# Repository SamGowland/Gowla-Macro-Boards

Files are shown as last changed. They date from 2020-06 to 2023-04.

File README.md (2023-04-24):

# Gowla-Macro-Boards 

 - [Gowla Macro Board V1](#Gowla-Macro-Board-V1) <b> :heavy_check_mark: </b>
   - 9 Key Macro board for MX style switches.
 - [Gowla-Macro-eRGB](#Gowla-Macro-eRGB) <b> :heavy_check_mark: </b>
   - 9 Key Macro Board with easy underglow RGB and Rotary Encoder support.
 - [MEK-Light | Tapedeck - Soon to be available, following QMK approval 2023 </b>](#MEK-Light-RGB) <b>:x:</b>
   - 12 Key editing keyboard with 60mm fader or 30mm + oled, two rotary encoders and underglow lighting. 
 - [Gowla Keyboard-1](#Gowla-Keyboard-1) <b>:x:</b>
   - 44 key Ortho Keyboard built around the Pi Pico with Encoders, Sliders and Glow. In the works. 
   
<b> :heavy_check_mark: Available</b> <b>:x: Not Available</b>

<i> For fully built macro keyboards with cases, follow my [eBay store](https://www.ebay.co.uk/usr/gowla.2014/) as these will only be listed when I have parts available. </i>

<p align="center">
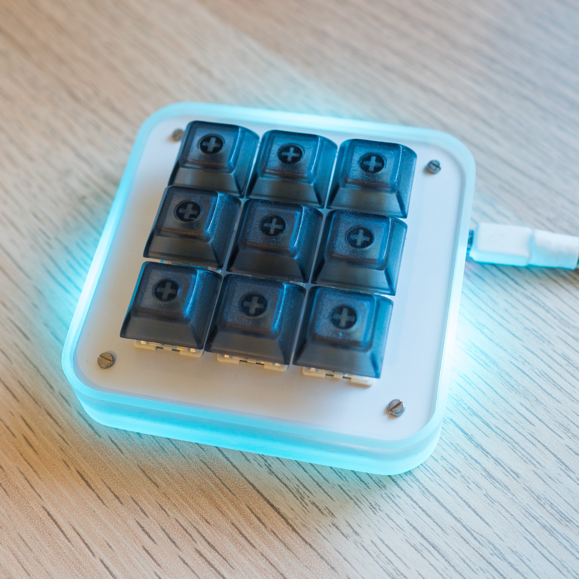
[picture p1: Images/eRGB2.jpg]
 
 
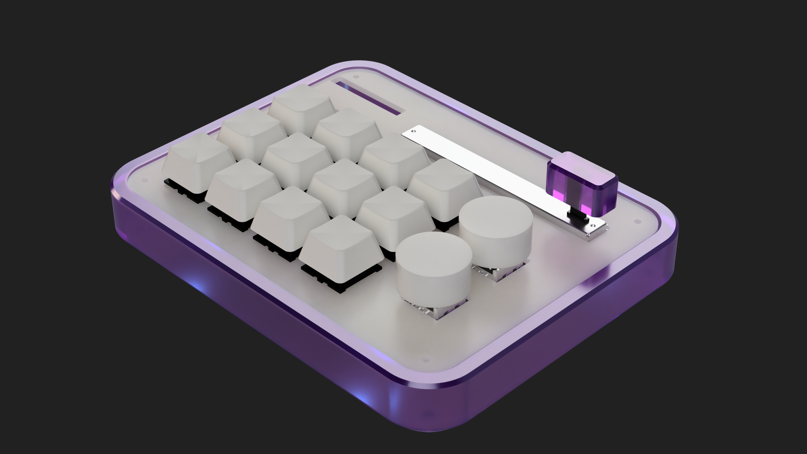
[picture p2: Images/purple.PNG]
 
</p>

 ---

# Gowla-Macro-Board-V1

Version 1 PCB is where this project all started and is available to buy, it's fully supported in QMK and super simple to put together! Great for practicing your soldering skills and getting started into mechanical keyboards. 

<p align="center">
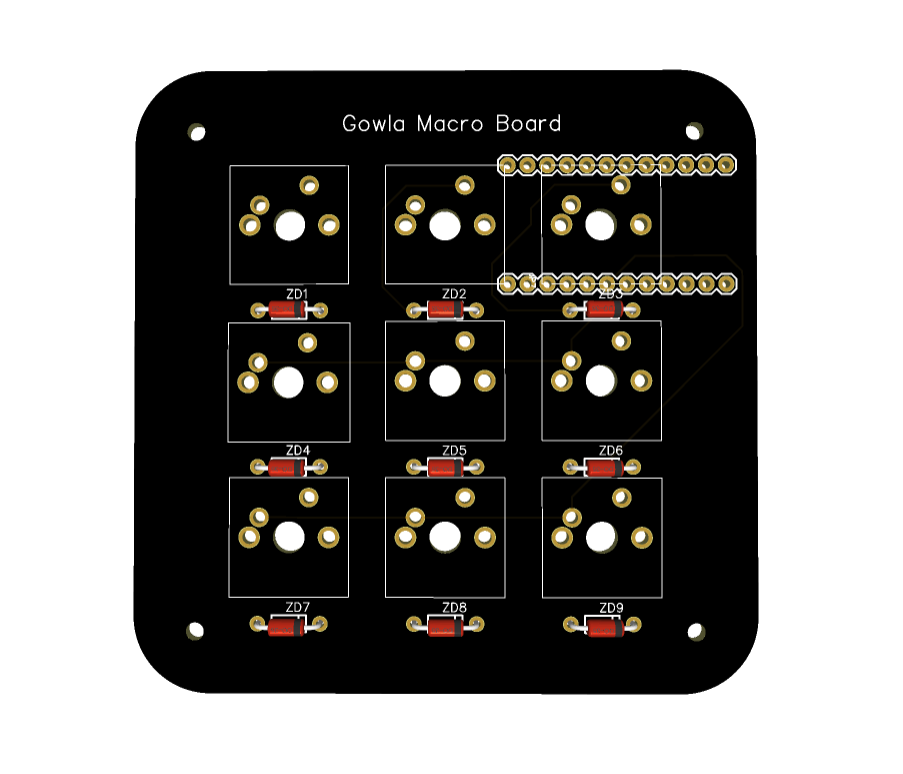
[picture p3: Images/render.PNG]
  
</p>

## Purchase

To purchase a PCB for DIY assembly and to support this project please visit my [eBay Page](https://www.ebay.co.uk/usr/gowla.2014/).

For additional options such as plates, hardware, RGB and more visit the <b>new!</b> multi variation page : [Variations eBay Page](http://www.ebay.co.uk/itm/164521787563)

## Required Parts

- 1 x Pro Micro ATMEGA32U4 5V 16MHz (Micro USB) - Sparkfun/Clone Size
- 9 x 1N4148 Diodes.
- 9 x PCB or Plate Mount Switches (Cherry MX or Clones).
- 9 x Key Caps.
- 8 x *<i>M2, 6mm (min) to 10mm (max) body length + 3mm thread Stand Off Spacers Male-to-Female</i>
  
  > Please note there's a variety of different hardware options. At a minimum you will need your PCB 6mm off the ground, though for the best compatibility I would recommend 8mm. 

## Assembly

Asssembly will require the use of a soldering iron, solder and some tape is recommended for holding components. <b>The order of assembly is important for the complete 9 switches. </b>

 1. Start by folding the legs of your diodes, with approx 3mm of space either side of the diode in wire. 
 
 2. Pull all diodes through the pcb holes, making sure the direction of the diode matches the image printed on the PCB. With the black mark in the direction towards the line. 
 
 3. Solder your diode legs and then cut the excess, leaving a little length for error. 
 
 4. Next solder in your top 3 switches. 
 
 5. Then solder in and/or socket your pro micro, you will at a minimum need the [headers](https://i.ebayimg.com/images/g/YPwAAOSwV3JeY9c1/s-l1600.jpg) provided with most when ordered. Making sure the pro micro usb is pointing outwards away from PCB and on the underside of the PCB. 
 
 <p align="center">
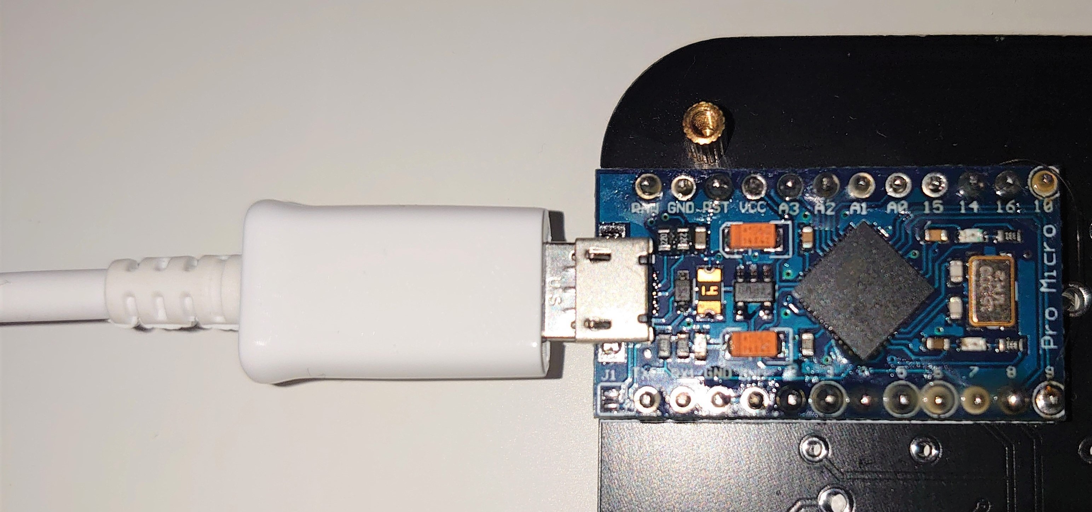
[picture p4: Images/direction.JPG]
  
</p>
 
 6. Once the Pro Micro is in, continue to solder your remaining switches. 
 
 7. Finish by adding key caps and screws, then move onto programming or flashing the firmware.
 
 <p align="center">
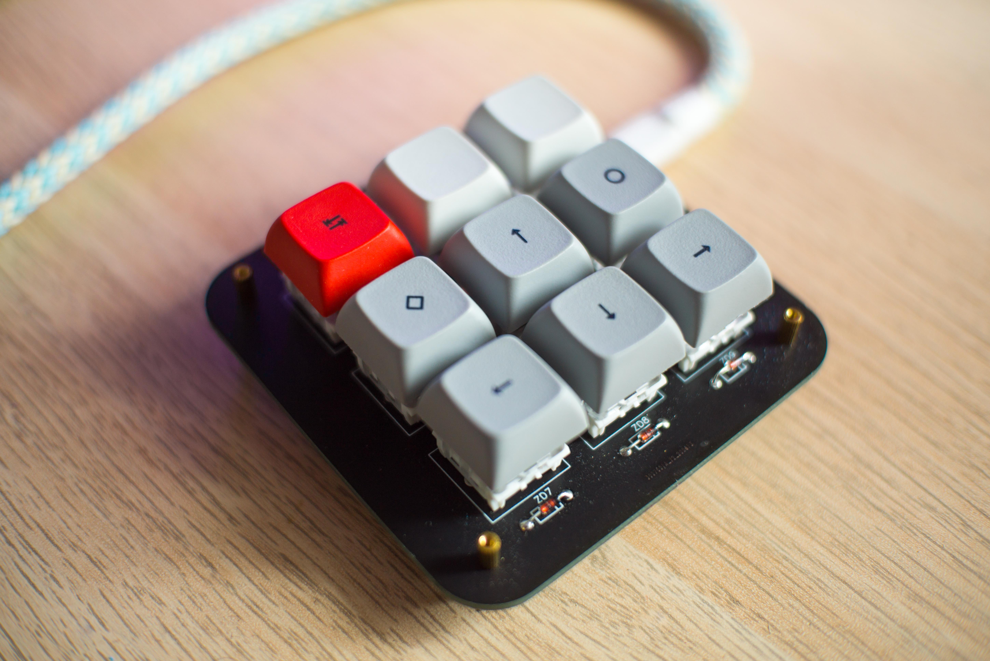
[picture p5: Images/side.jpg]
  
</p>

---
## Simple Programming

You can build and compile new keyboard layouts most simply by using the web configurator : https://config.qmk.fm/#/gowla/LAYOUT_ortho_3x3

For more advanced programming follow the [QMK tutorials](https://beta.docs.qmk.fm/tutorial).

The [default build](https://github.com/qmk/qmk_firmware/tree/master/keyboards/gowla) is also available for use through QMK toolbox and files available within the QMK Firmware repository.

## Prebaked Firmware Profiles

 1. <a href='Hex Profiles/gowla_default.hex'> Default </a><br>
 2. <a href='Hex Profiles/arrows_media.hex'> Arrows & Media </a><br>
 3. <a href='Hex Profiles/functions_gui.hex'> Fuctions & Gui </a><br>
 4. <a href='Hex Profiles/nav_media.hex'> Navigation and Media </a><br>
 
 <i>Images for each of the profiles can be found in the [images directory](https://github.com/SamGowland/Gowla-Macro-Board/tree/master/Images).</i>
 
 If you wish to add your template for other users to use, please create 
 [an issue](https://github.com/SamGowland/Gowla-Macro-Board/issues), prefixing the
issue name with "Profile".

## Flashing a Pro Micro

To flash a pro micro with your newly built or prebaked firmware you must get it into DFU mode, short the reset and ground pins. Shorting once will put into DFU for 750ms, you can use QMK toolbox to dectect DFU and automatically flash once detected. 

Double resets, to keep the pro micro in DFU mode for longer short reset and ground twice quickly. This will keep it in DFU mode upto 8 seconds allowing you to manually flash the pro micro with QMK toolbox or AVRdudess GUI. 

You can use either of the following software to flash your pro micro. 
- [QMK toolbox](https://github.com/qmk/qmk_toolbox/releases).
- [AVRdudess](https://blog.zakkemble.net/avrdudess-a-gui-for-avrdude/).

---

## Top Plates

To further improve aesthetics an additional top plate is available to buy, top plates only come in gloss white from now on. Matte blacks were experimented with but scratch too easily. <b> These are available to buy now </b> at the new multi variation ebay listing, along with new white PCBs:  [eBay Page](http://www.ebay.co.uk/itm/164521787563)

Top plates require additional hardware, M2 hardware is inculuded when purchasing a Top Plate. 3mm spacers between the plate and the PCB. 8mm spacers and 8mm M2 machine screws. 

<p align="center">
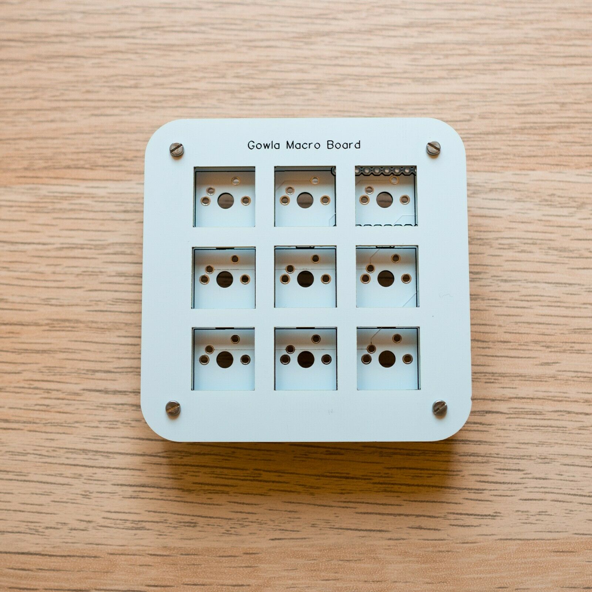
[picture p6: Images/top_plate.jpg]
  
</p>

## Case in the works

Currently I am working towards a low cost case design and intend it to look like the render below. The case will work with any updated PCB designs. So far I have designed and 3D printed these. But to improve surface finish and reduce print time the top plates will be laser cut. Top plates will be available in either black and white. 

STL files are provided for the case design within this repository. However you will need some additonal M2 hardware and no assembly instructions are currently provided. 

<p align="center">
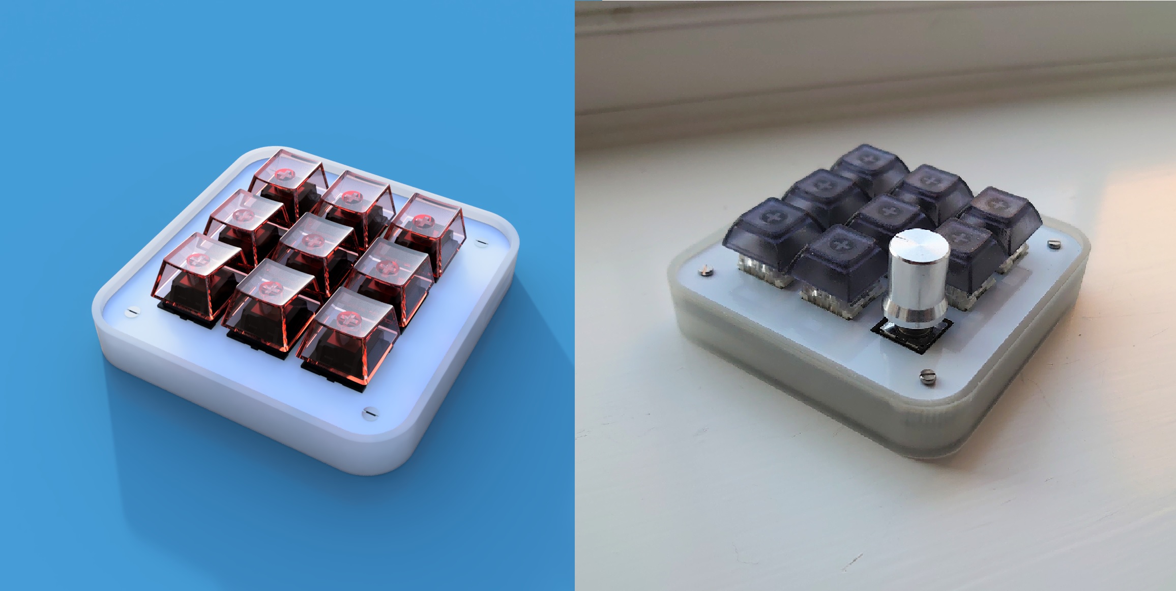
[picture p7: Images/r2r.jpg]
  
</p>

---

# Gowla-Macro-eRGB

Designed to make RGB lighting as easy as possible and add support for an optional rotary encoder (Alps EC11)

On sale now through the [Variations eBay Page](http://www.ebay.co.uk/itm/164521787563)

eRGB is backwards compatible with V1 firmware, <b> you maybe recieve an eRGB board if you order pcb only </b>. These can be assembled as V1s or with the additional features. 

<p align="center">
  
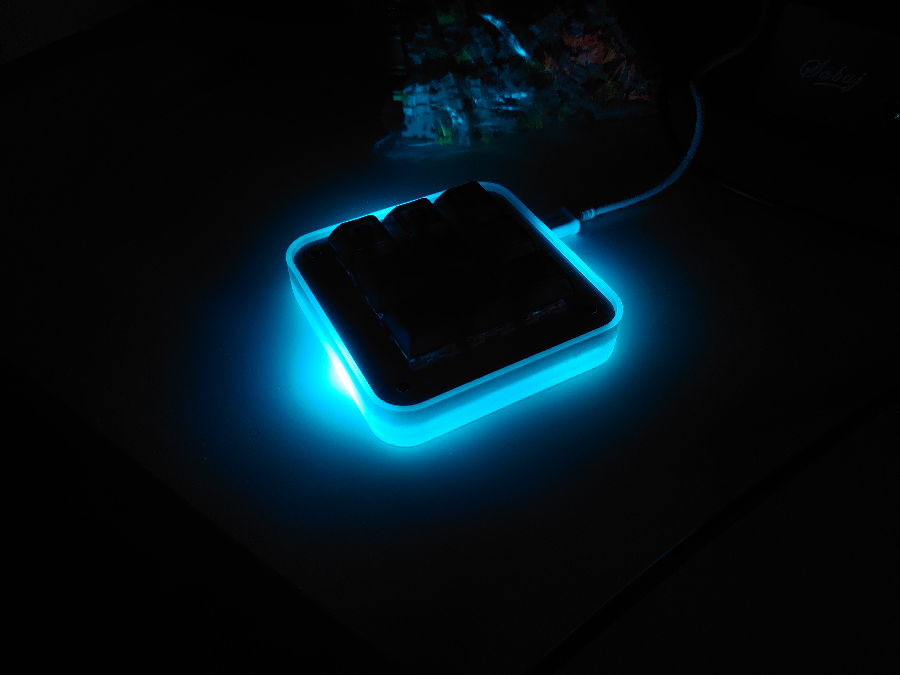
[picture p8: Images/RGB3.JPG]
 
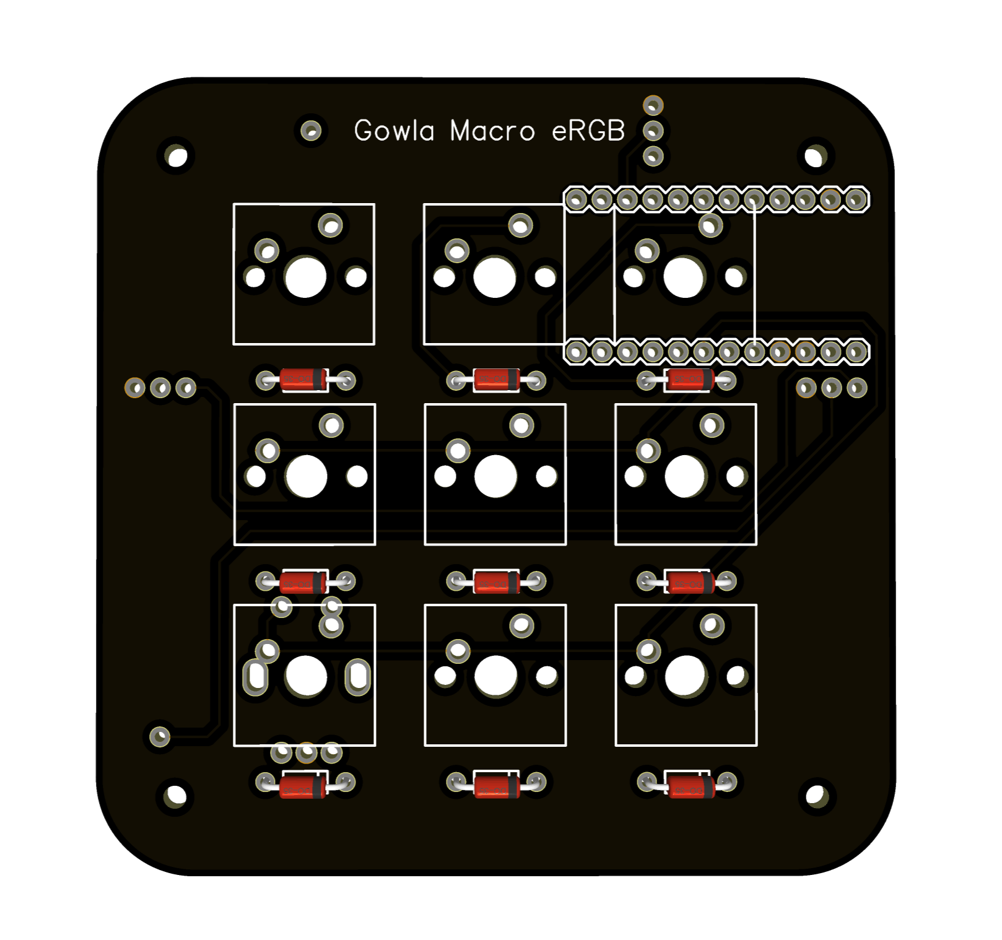
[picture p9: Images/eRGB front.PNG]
  
</p>

Some Assembly Tips (In order): 

When building take your time, and keep in mind not to block anything off before soldering it :)

- Start by soldering all your diodes into place. 
- Solder the pin headers for your pro micro but not the pro micro it's self yet. 
- Connect the plate to the PCB with 3mm spacers using the 8mm M2 scerws between the PCB and Top Plate or push switches through plate first. Head of machine screw will be on top the top plate, going through both the spacer and PCB into the 8mm bottom spacer. You may need to trim the height of the headers on the top side so they don't block the top plate. You could place switches into top plate first either. 
- Push your switches into plate and through the PCB, soldering down all your switches or 8 if your doing bottom left as rotary encoder. 
- Solder the Pro micro to the pin headers. 
- Solder RGB LEDs and rotary encoder if applicable. 

## eRGB Firmware

The firmware process for eRGB is a bit more involved at the moment, until it's no longer early access. 

Example firmware is provided within [eRGB Folder](https://github.com/SamGowland/Gowla-Macro-Boards/tree/master/eRGB/).

Please note, the following lines differ in config.c for black and white PCBs, black eRGB are an older revision. 

For white PCBs encoder and RGB pins should match this, surrounding code is not shown just update the 3 lines. 

```c
/* RGB */
#define RGB_DI_PIN B6

...

/* Rotary Encoder*/
#define ENCODERS_PAD_A { B2 }
#define ENCODERS_PAD_B { B3 }
```

 ---

# MEK-Light-RGB

coming very soon. 

[Demo Video](https://www.youtube.com/watch?v=-6GdU5GIuqY).

<p align="center">
  
</p>

## Kit Options

- Build Kit 1: 
  - Link: 
  - Included Parts: PCB, Top Plate, Alps 60mm Dual Linear Pot, 3 x RGB LEDs, Diodes, 330R Resistor, M2 Assembly Hardware
  - Required Parts: Pro Micro 5V, 2 x Alps EC11, MX Switches, Keycaps
- Build Kit 2: 
  - Link: 
  - Included Parts: Kit 1, Bottom Case, 2 x Alps EC11
  - Required Parts: Pro Micro 5V, MX Switches, Keycaps

## Build Guide

Straight forward but will require the use of a soldering iron, solder, wire cutters, time and maybe some tape for holding components. Before starting check you have all the required parts. 

Note: Order of Assembly matters, don't start with switches. 

<p align="center">
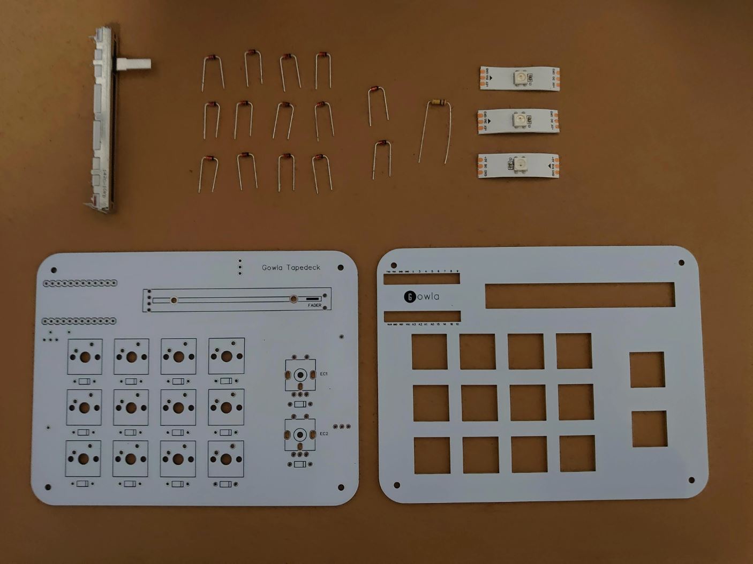
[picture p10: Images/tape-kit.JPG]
  
</p>

1. Start by folding the legs of your 14 diodes, with approx 3mm of space either side of the diode in wire.

2. Pull all diodes through the PCB holes, making sure the direction of the diode matches the image printed on the PCB. Note the direction of diodes is different for the two encoders.

3. Solder your diode legs and cut the excess.

4. Solder the 330 Ohm resistor marked on the backside. 

5. Then solder in and/or socket your pro micro, you will at a minimum need the headers provided with most when ordered. Making sure the pro micro usb is pointing outwards away from PCB and on the underside of the PCB.

6. Solder the Encoders to the PCB.

7. Solder the 60MM fader to the PCB. 

8. Grab your top plate, place the long M2 machine head screws through the plate and thread the 2mm spacer up to the top plate just like this image. 

9. Attach your top plate to the PCB by threading the gold standoffs on the machine head screws going through both the top plate and PCB. 

<p align="center">
  
</p>

10. Push down your switches into the top plate, soldering the pins connected to the PCB. 

11. Place your 3 x adhesive RGBs between the marked positions on the backside of the PCB, ensuring they match the correct direction (DI to DO) and solder between the pad and bridge. As shown here below. 

<p align="center">
  
</p>

12. Dress up with Keycaps and Knobs. Then Flash an example or custom firmware and play with your board! 

 ---
 
 ## Usage and EULA 

Design and profiles are made freely available for personal usage only and no further commercial usage. By downloading or using files within this repository users agree to not resell or redistribute the designs or files. 

## Additional Use Cases

Find additional use cases for the PCB within the [Uses directory](https://github.com/SamGowland/Gowla-Macro-Board/tree/master/Uses), a nice example is [dan-r's](https://github.com/dan-r) IR Remote use case. 

---

## Maintainers

* [Gowla](https://github.com/SamGowland)

## Getting Help

Please report issues you encounter to the
*Gowla-Macro-Board*
[Issue Tracker](https://github.com/SamGowland/Gowla-Macro-Board/issues), prefixing the
issue name with "Macro".

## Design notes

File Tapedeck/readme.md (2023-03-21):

# Gowla Tapedeck

Image of Tapedeck

4x4 12 Key Macro Board with 60MM Slider, RGB and 2 X Rotary Encoders. For use with QMK, designed and sold by Gowla.

* Keyboard Maintainer: [Gowla](https://github.com/SamGowland/)
* Hardware Supported: Pro Micro ATmega32U4, Cherry MX Switches, Alps 60MM Slider
* Hardware Availability: [Repo](https://github.com/SamGowland/Gowla-Macro-Boards)

Make example for this keyboard (after setting up your build environment):

    make tapedeck:default
    
Flashing example for this keyboard:

    make tapedeck:default:flash

See the [build environment setup](https://docs.qmk.fm/#/getting_started_build_tools) and the [make instructions](https://docs.qmk.fm/#/getting_started_make_guide) for more information. Brand new to QMK? Start with our [Complete Newbs Guide](https://docs.qmk.fm/#/newbs).

## Bootloader

Enter the bootloader in 3 ways:

* **Bootmagic reset**: Hold down the top-left key (underneath the Pro Micro) and plug in the keyboard. This will also clear EEPROM, so it is a good first step if the keyboard is misbehaving.
* **Physical reset**: Remove the back plate and short the `RST` and `GND` pins on the Pro Micro.
* **Keycode in layout**: There is no key mapped to `QK_BOOT` in the pre-created keymaps, but you may assign this key in any keymaps you create.

As a Pro Micro-compatible board, the Gowla Tapedeck uses `caterina` as its bootloader by default. Many popular Pro Micro alternatives like the Elite-C, Bit-C, Sea-Micro, Puchi-C etc should be flashed with a different bootloader such as `atmel-dfu`.

If the incorrect bootloader is specified, bootmagic reset and the `QK_BOOT` keycode will not work.

To avoid this problem, set the correct bootloader in your custom keymap's `rules.mk` file before compiling, or flash using an appropriate target (e.g. `make tapedeck:default:dfu`). See [flashing instructions and bootloader information](https://docs.qmk.fm/#/flashing) for more details.

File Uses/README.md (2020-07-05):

# Gowla-Macro-Board - Use Cases
---

Below is a list of additional use cases for the macro board. For each usage, please read the included readme. 

1. [IR-Remote-Nano](IR-Remote-Nano)

## Submit a Usage

Submit a usage by cloning or creating a fork of the repository, then create a new folder in [Uses](https://github.com/SamGowland/Gowla-Macro-Board/blob/master/Uses) and populate this folder with your project. Your folder must contain a readme.md. Add your usage to the list. Then create a pull request. 

---

## Maintainers

* [Gowla](https://github.com/SamGowland)

## Getting Help

Please report issues you encounter to the
*Gowla-Macro-Board*
[Issue Tracker](https://github.com/SamGowland/Gowla-Macro-Board/issues), prefixing the
issue name with "Macro".

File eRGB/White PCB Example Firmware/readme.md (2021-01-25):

# Gowla Macro eRGB

<p align="center">
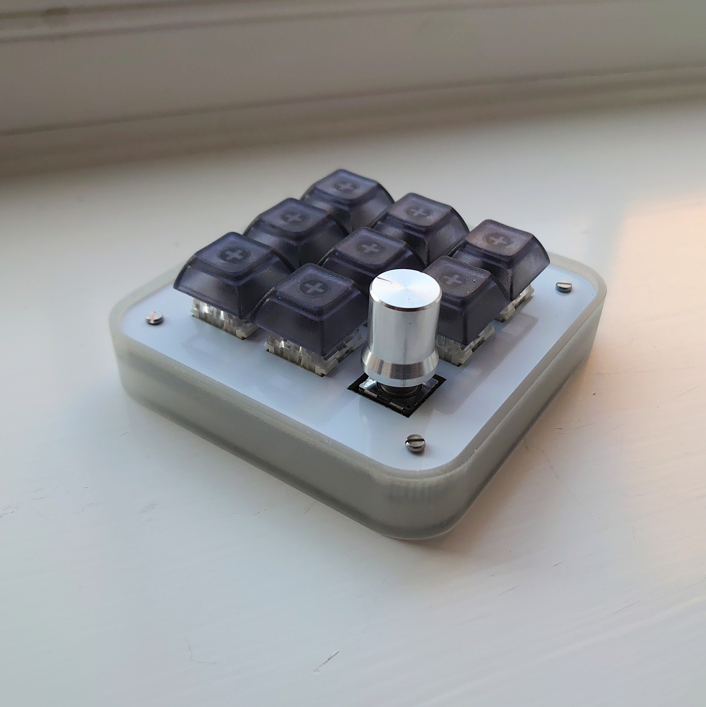
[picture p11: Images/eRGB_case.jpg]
  
</p>

Simple Compact 3x3 Macro Board for use with QMK, designed and sold by Gowla.

* Keyboard Maintainer: [Gowla](https://github.com/SamGowland/)
* Hardware Supported: Pro Micro ATmega32U4, Cherry MX Switches
* Hardware Availability: [Repo](https://github.com/SamGowland/Gowla-Macro-Boards)

Make example for this keyboard (after setting up your build environment):

    make gowla/e_rgb:default

See the [build environment setup](https://docs.qmk.fm/#/getting_started_build_tools) and the [make instructions](https://docs.qmk.fm/#/getting_started_make_guide) for more information. Brand new to QMK? Start with our [Complete Newbs Guide](https://docs.qmk.fm/#/newbs).

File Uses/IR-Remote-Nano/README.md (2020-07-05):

# IR-Remote-Nano: Arduino Nano + IR Remote
---

## Why

Shows that the board is compatible with an Arduino Nano - the overhanging pins need to be snapped off but it works if you don't require the USB host functionality for some reason.

I use it to control an iPod dock on my desk, as its nicer to use than the original remote, which was blu-tacked to the desk.

## Images

<table>
  <tr>
    <td>
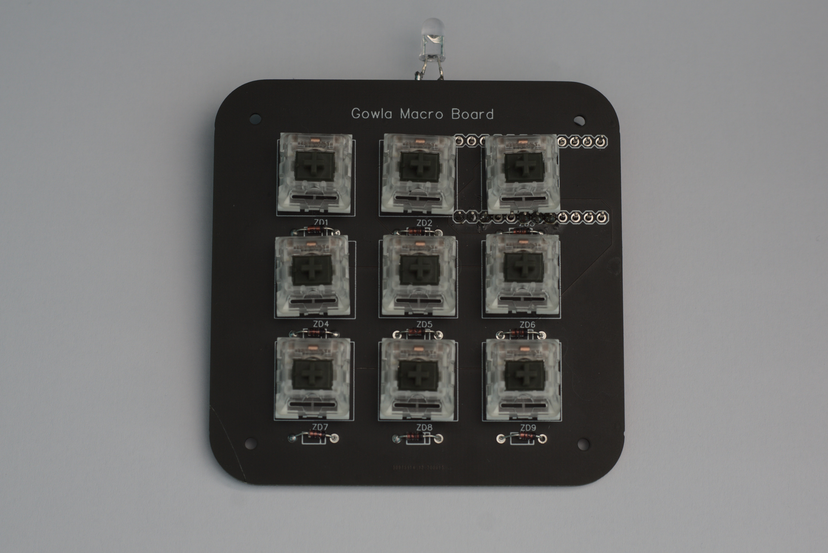
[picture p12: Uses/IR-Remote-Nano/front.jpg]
      
    </td>
    <td>
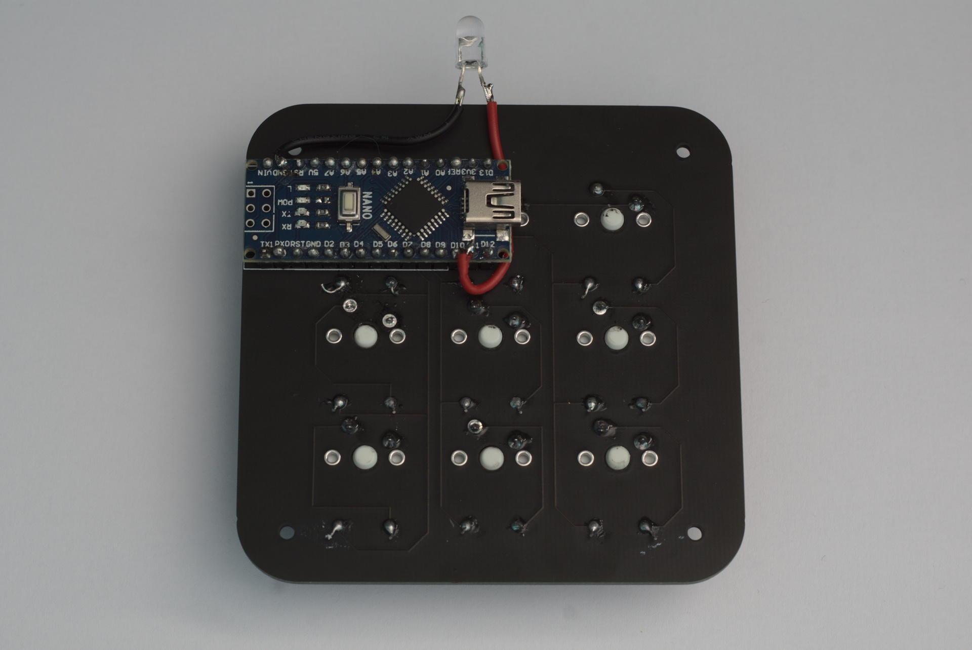
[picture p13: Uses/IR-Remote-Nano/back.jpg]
      
    </td>
  </tr>
</table>
  
## Code
1. [Basic IR Control with IRMP](basicir.ino)

## Maintainer

* [dan-r](https://github.com/dan-r)

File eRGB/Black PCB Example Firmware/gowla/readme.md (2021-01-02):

# Gowla Macro Board

Simple Compact 3x3 Macro Board for use with QMK, designed and sold by Gowla.

* Keyboard Maintainer: [Gowla](https://github.com/SamGowland/)
* Hardware Supported: Pro Micro ATmega32U4, Cherry Mount Switches
* Hardware Availability: [Repo](https://github.com/SamGowland/Gowla-Macro-Board)

Make example for this keyboard (after setting up your build environment):

    make gowla:default

See the [build environment setup](https://docs.qmk.fm/#/getting_started_build_tools) and the [make instructions](https://docs.qmk.fm/#/getting_started_make_guide) for more information. Brand new to QMK? Start with our [Complete Newbs Guide](https://docs.qmk.fm/#/newbs).

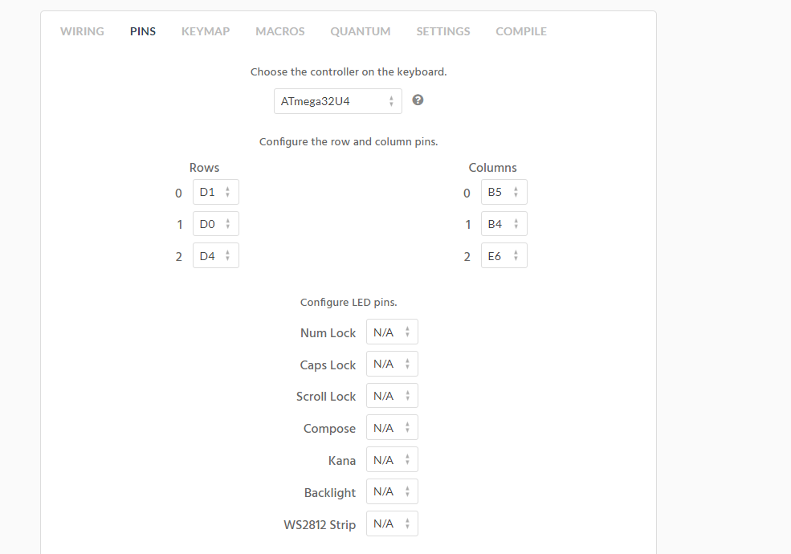
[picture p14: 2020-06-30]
Images/pins.PNG

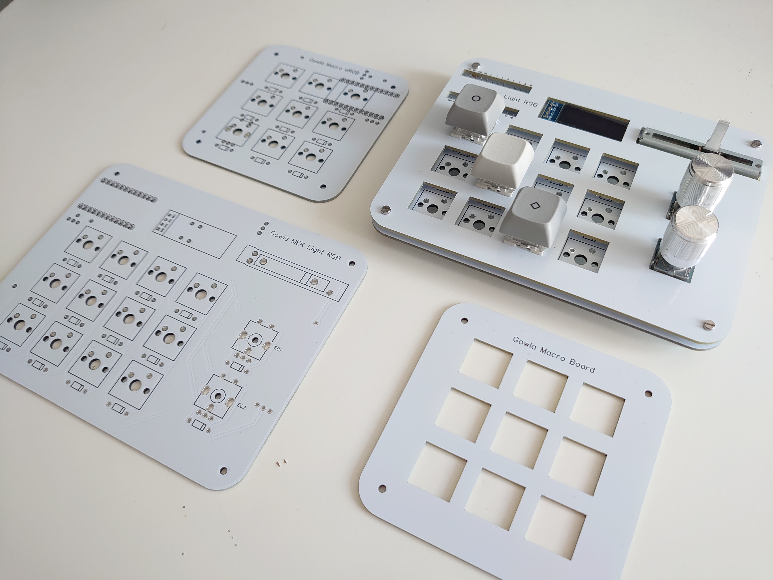
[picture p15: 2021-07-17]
Images/boards.JPG

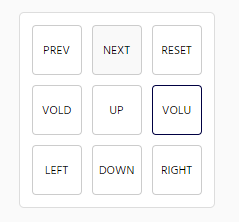
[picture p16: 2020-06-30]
Images/am.PNG

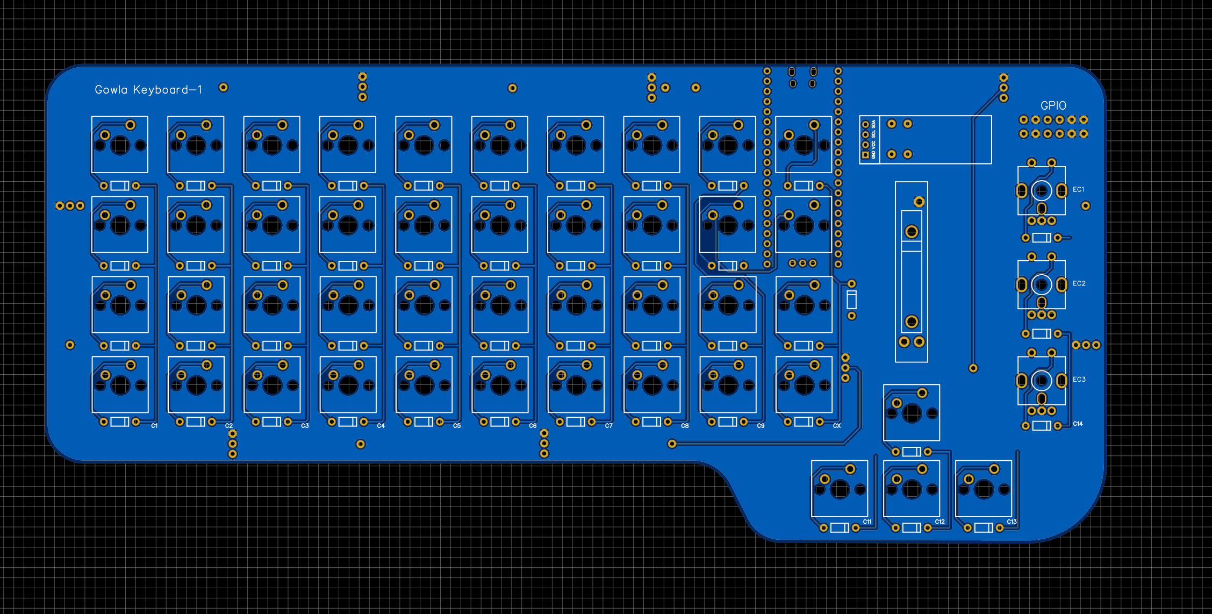
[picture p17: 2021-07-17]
Images/pikey.png

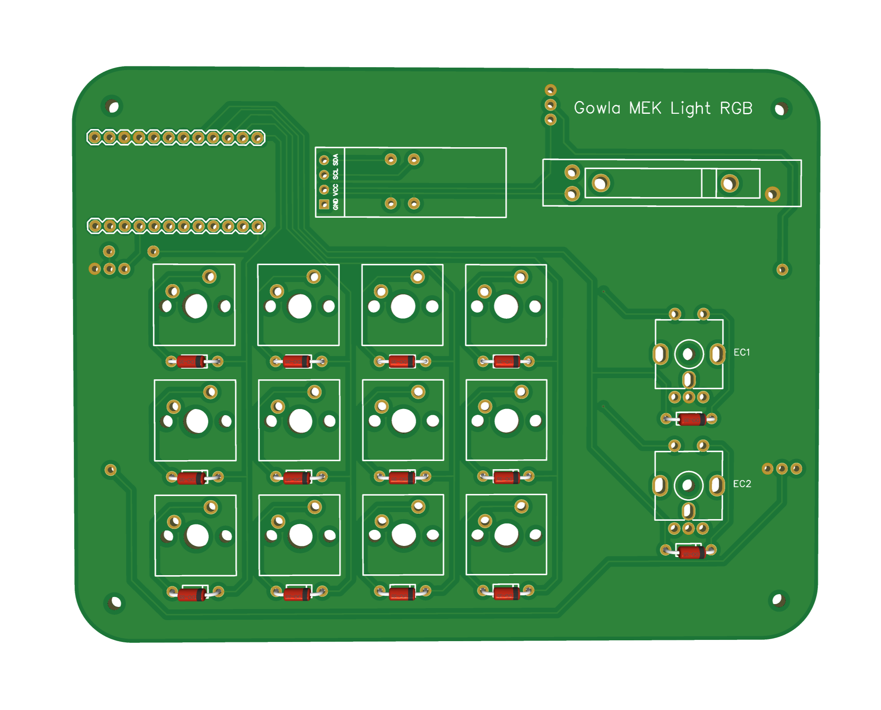
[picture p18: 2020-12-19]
Images/MEK Light.PNG

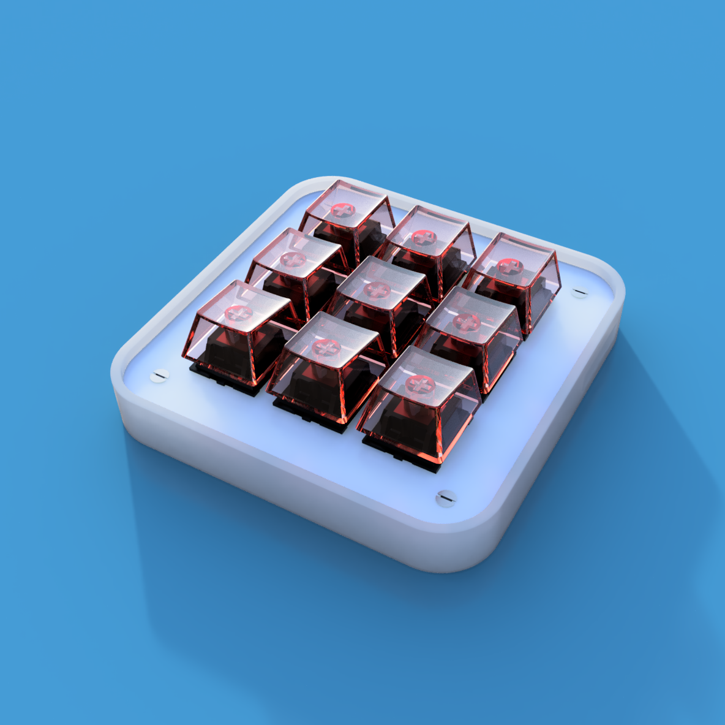
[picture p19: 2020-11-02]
Images/case_d2.PNG

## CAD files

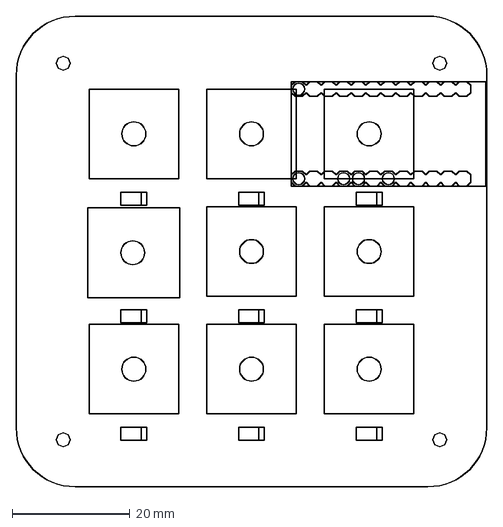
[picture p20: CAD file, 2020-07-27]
Gerbers/Gowla_2020-07-07_01-06-41.dxf
80.0 x 80.0 mm

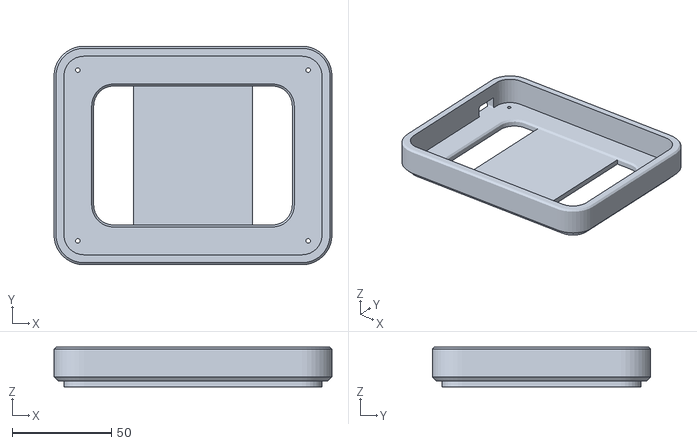
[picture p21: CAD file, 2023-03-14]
STL/MEK-L-tapedeck-bottom.stl
140.0 x 110.0 x 20.0

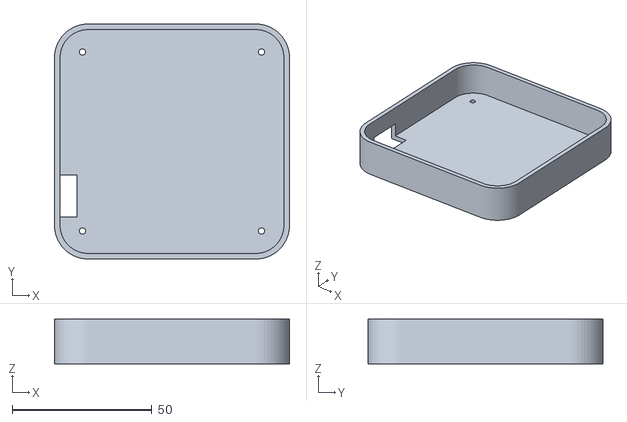
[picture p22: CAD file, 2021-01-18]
STL/bottom_case_m2.stl
84.0 x 84.0 x 16.0

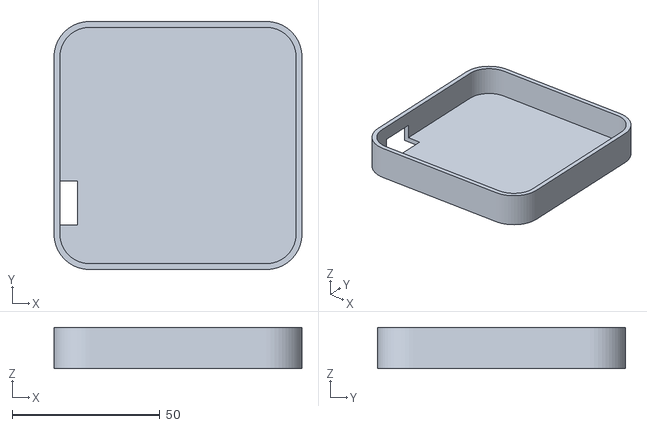
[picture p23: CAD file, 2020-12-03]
STL/bottom_case.stl
84.0 x 84.0 x 14.0

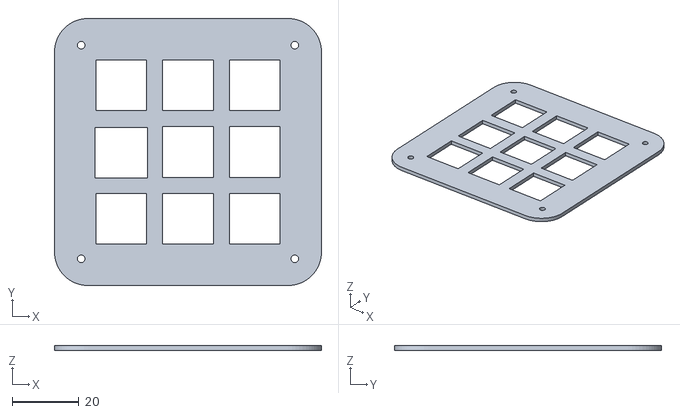
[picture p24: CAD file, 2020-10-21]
STL/top_plate.stl
80.0 x 80.0 x 1.50

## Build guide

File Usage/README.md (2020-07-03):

# Gowla-Macro-Board - Usage
---

Below is a list of additional uses for the macro board. For each usage, please read the included readme. 

1. New usage. 

## Submit a Usage

Submit a usage by creating a fork of the repository, then create a new folder in [Usage](https://github.com/SamGowland/Gowla-Macro-Board/blob/master/Usage) and populate this folder with your project. Your folder must contain a readme.md. Add your usage to list of the readme. Then create a pull request. 

---

## Maintainers

* [Gowla](https://github.com/SamGowland)

## Getting Help

Please report issues you encounter to the
*Gowla-Macro-Board*
[Issue Tracker](https://github.com/SamGowland/Gowla-Macro-Board/issues), prefixing the
issue name with "Macro".

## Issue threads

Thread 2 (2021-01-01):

Some feedback/suggestions for V1

benedict-odonovan, 2021-01-01:
Hi Gowla!

I ordered a PCB and top layer from your eBay store and I only got around to putting it together today as my first attempt at a custom keyboard. Admittedly my soldering leaves something to be desired but it was great fun and the board looks and works great.

Some suggestions if you're interested:

- You may want to look at providing/suggesting larger spacers for the bottom of the board. I socketed my pro micro rather than soldering it directly to the board and it stands too proud from the board for the provided (8mm?) standoffs. I ended up combining the 3mm and 8mm standoffs to fit the pro micro underneath.
- Space for a reset button on the board might be handy as an option
- The instructions don't reference the optional top layer at all so I wasn't sure whether it sat above or below the switches
- More pictures to accompany the instructions would be helpful!

SamGowland, 2021-01-01:
Thanks for your suggestions, it's greatly apperciated and helpful to me for improving the documentation :)

8mm standoffs should give you enough clearance using a socketed pro micro. However I may have given you 6mm standoffs by accident, which I use for cases.

**Sorry if this the case**, you can measure them and if they are 6mm contact me through ebay and will post you some 8mm's.

The optional top just gets placed on top the pcb, with 3mm M2 spacers between the top part and the PCB. It's a decroative add on and so can be added after switches are soldered, when no keycaps are attached.

And yes a dedicated button could be nice!

Closed 2021-01-20.

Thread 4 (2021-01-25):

Easy RGB Extension for V1 PCBs

benjgorman, 2021-01-25:
Hey Sam, Great little PCB, super easy to get working. I'm used to working with Arduino, but new to QMK, and your guide was super easy to follow. I'm using this for a little streamdeck for using with OBS when online teaching.

Your PCB footprint/dimensions perfectly allows for a 24 LED Neopixel ring (NeoPixel Ring - 24 x WS2812 5050 RGB LED with Integrated Drivers). Figured I would add the images here in case it was useful for building future versions. I've just wired the 5V pin to VCC, and then GND and Pin 14 for the Data Input.

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

SamGowland, 2021-01-25:
Thanks Ben :)

Always enjoy seeing builds and any hacking!

QMK is great, just the intial hurdle of a build enviroment and then it's smooth sailing. If you happen to make any complex firmware builds please do consider sharing them. You can do this here or within the QMK repo itself.

I will have some SLA printed cases available soon, if they happen to interest you. There's a picture in the repo. Though with your add on they might not fit. The STL for the cases are available, which you could use to make the case a bit taller so your extra would fit and use an on demand print service.

eRGB adds encoders and RGB lights, just uses the cutable adhesive 2812 strips. Just cut and stick between the markers on the PCB and solder a bridge across. It works really well.

MEK Light, I have through hole PCBs at the moment and once tested will put some on the ebay page if intersted.
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

Closed 2021-07-16.

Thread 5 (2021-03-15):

Top plates and soldering order/switch position

jsribeiro, 2021-03-15:
Hi!

Just got one of the PCBs and it looks great! Very well built and great finish.

I just have a doubt regarding key switch positions when using a top plate. From pictures, and from what makes more sense, the switches are placed above the top plate. This way the spacing is perfect and the plate takes on the weight of the key presses.

However, I can't seem to find a way to make this happen. Since I need to 1) solder at least one of the switches in order to 2) solder the Pro Micro, if I place the switch above the plate, I won't be able to solder the Pro Micro.

Should the plate go over the switches, then? If so, are the 2mm spacers included in the package the correct length?

Or am I thinking the wrong way about something? :)

Thanks!

SamGowland, 2021-03-15:
Hi :)

This depends if you have a normal or eRGB.

Normal (v1) top plate is purely decorative and can be added on to existing builds. Just by removing key caps and sliding over.

eRGB top plate is functional as well, it will hold plate mount switches and _so the build process is different_.

Following the instructions for eRGB take note of the fact you solder the _headers of the pro micro first_, then switches and then pro micro otherwise like you have said you will be unable to solder if this is done out of order.

Hope this helps.

jsribeiro, 2021-03-15:
Ohhhh...

Even though I have a regular one, it slipped my mind to solder just the Pro Micro headers, because I had already soldered them to the Pro Micro (which I was already using in a breadboard for other stuff).

So yes, it's obvious now... Solder the headers, then solder the switches with the top plate underneath, and finally solder the Pro Micro to the headers...

Thanks... I feel dumb, now... :)

SamGowland, 2021-03-15:
Yes that's the best way :) you may find you have to snip some of the headers if they are too high as well.

And you can save soldering time by just soldering the required pins for the version of board (3,4,5,7,8,9) for v1. These can be viewed through the gerber or found in the code. But if unsure just solder all pins.

If you have a built v1, the top plate for that can be added just by pushing over the top with keycaps removed. Depending on how straigt all the switches are you may have to rotate or flip the plate.

Closed 2021-03-15.

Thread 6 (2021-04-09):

2D drawings for the top plate

UweZiegenhagen, 2021-04-09:
Hi Sam, I'd like to cut some veneer for the top plate with a laser cutter and need a 2D vector drawing of the top plate. Do you have some drawing?

SamGowland, 2021-05-06:
Hi 😄  Sorry for my delay, but you can find STL for the top plate part here https://github.com/SamGowland/Gowla-Macro-Boards/blob/master/STL/top_plate.stl

Along with STL for the bottom part. Hope this helps!

Likewise some gerbers are available in /Gerbers/ these can be opened in most EDA software.

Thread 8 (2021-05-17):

OLED on RGB boards

afonsoguerra, 2021-05-17:
Hi,

While one waits for the next board version to be tested, I wonder if there are free pins on the eRGB to install a OLED display to show which layer one is on. From a quick glance I think pins 2 and 3 that should work for the SCK and SDA are busy already,  right?

Since this is implemented successfully in the new version, I just thought I'll ask.

SamGowland, 2021-05-18:
Hi :)

Unfortuantely the pins are used, however if you do not use the rotary encoder you could an SPI screen.

http://www.phreakmonkey.com/2016/01/generic-5-128x64-oled-spi-display-with.html

See this image for which pins are used.

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

Kind Regards

afonsoguerra, 2021-05-19:
Thanks! I'm loving the rotary encoder though... I'll probably just colour-code the underglow then. Thanks for confirming that.

Closed 2021-05-19.

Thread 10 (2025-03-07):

Unable to build e_rgb firmware on newer QMK MSYS versions.

mnotgninnep, 2025-03-07:
In needing to replace my arduino micro on my Gowla e_rgb, I discovered that newer versions of QMK MSYS have depreciated several things used in the e_rgb firmware leading to it being unable to build, most critically, config_common.h has been removed in its entireity. See here: https://github.com/qmk/qmk_firmware/blob/e99b7f240aacd4d9a0182396533a3e972ea1f9a8/docs/ChangeLog/20230528.md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

Please would you update the firmware to be able to build on newer versions of the software?

Let me know if you need any other information.

Thank you.

Here is the output from the console currently in QMK MSYS 1.10.0:

[michael@MICHAEL-E495 ~]$ qmk compile -kb gowla/e_rgb -km default
Traceback (most recent call last):
  File "C:/Program Files/QMK_MSYS/mingw64/lib/python3.12/site-packages/milc/milc.py", line 606, in __call__
    return self.__call__()
           ^^^^^^^^^^^^^^^
  File "C:/Program Files/QMK_MSYS/mingw64/lib/python3.12/site-packages/milc/milc.py", line 611, in __call__
    return self._subcommand(self)
           ^^^^^^^^^^^^^^^^^^^^^^
  File "C:/Users/michael/qmk_firmware/lib/python/qmk/cli/generate/version_h.py", line 39, in generate_version_h
    git_version = git_get_version() or current_time
                  ^^^^^^^^^^^^^^^^^
  File "C:/Users/michael/qmk_firmware/lib/python/qmk/git.py", line 23, in git_get_version
    git_describe = cli.run(git_describe_cmd, stdin=DEVNULL, cwd=repo_dir)
                   ^^^^^^^^^^^^^^^^^^^^^^^^^^^^^^^^^^^^^^^^^^^^^^^^^^^^^^
  File "C:/Program Files/QMK_MSYS/mingw64/lib/python3.12/site-packages/milc/milc_interface.py", line 121, in run
    return self.milc.run(command, capture_output, combined_output, text, **kwargs)
           ^^^^^^^^^^^^^^^^^^^^^^^^^^^^^^^^^^^^^^^^^^^^^^^^^^^^^^^^^^^^^^^^^^^^^^^
  File "C:/Program Files/QMK_MSYS/mingw64/lib/python3.12/site-packages/milc/milc.py", line 193, in run
    return subprocess.run(command, **kwargs)
           ^^^^^^^^^^^^^^^^^^^^^^^^^^^^^^^^^
  File "C:/Program Files/QMK_MSYS/mingw64/lib/python3.12/subprocess.py", line 550, in run
    stdout, stderr = process.communicate(input, timeout=timeout)
                     ^^^^^^^^^^^^^^^^^^^^^^^^^^^^^^^^^^^^^^^^^^^
  File "C:/Program Files/QMK_MSYS/mingw64/lib/python3.12/subprocess.py", line 1209, in communicate
    stdout, stderr = self._communicate(input, endtime, timeout)
                     ^^^^^^^^^^^^^^^^^^^^^^^^^^^^^^^^^^^^^^^^^^
  File "C:/Program Files/QMK_MSYS/mingw64/lib/python3.12/subprocess.py", line 1628, in _communicate
    self.stdout_thread.join(self._remaining_time(endtime))
  File "C:/Program Files/QMK_MSYS/mingw64/lib/python3.12/threading.py", line 1149, in join
    self._wait_for_tstate_lock()
  File "C:/Program Files/QMK_MSYS/mingw64/lib/python3.12/threading.py", line 1169, in _wait_for_tstate_lock
    if lock.acquire(block, timeout):
       ^^^^^^^^^^^^^^^^^^^^^^^^^^^^
KeyboardInterrupt

During handling of the above exception, another exception occurred:

Traceback (most recent call last):
  File "<frozen runpy>", line 198, in _run_module_as_main
  File "<frozen runpy>", line 88, in _run_code
  File "C:/Program Files/QMK_MSYS/mingw64/bin/qmk.exe/__main__.py", line 7, in <module>
  File "C:/Program Files/QMK_MSYS/mingw64/lib/python3.12/site-packages/qmk_cli/script_qmk.py", line 86, in main
    return_code = milc.cli()
                  ^^^^^^^^^^
  File "C:/Program Files/QMK_MSYS/mingw64/lib/python3.12/site-packages/milc/milc_interface.py", line 161, in __call__
    return self.milc()
           ^^^^^^^^^^^
  File "C:/Program Files/QMK_MSYS/mingw64/lib/python3.12/site-packages/milc/milc.py", line 605, in __call__
    with self:
         ^^^^
  File "C:/Program Files/QMK_MSYS/mingw64/lib/python3.12/site-packages/milc/milc.py", line 780, in __exit__
    print(exc_type)
  File "C:/Program Files/QMK_MSYS/mingw64/lib/python3.12/site-packages/colorama/ansitowin32.py", line 47, in write
    self.__convertor.write(text)
  File "C:/Program Files/QMK_MSYS/mingw64/lib/python3.12/site-packages/colorama/ansitowin32.py", line 177, in write
    self.write_and_convert(text)
  File "C:/Program Files/QMK_MSYS/mingw64/lib/python3.12/site-packages/colorama/ansitowin32.py", line 205, in write_and_convert
    self.write_plain_text(text, cursor, len(text))
  File "C:/Program Files/QMK_MSYS/mingw64/lib/python3.12/site-packages/colorama/ansitowin32.py", line 210, in write_plain_text
    self.wrapped.write(text[start:end])
  File "C:/Program Files/QMK_MSYS/mingw64/lib/python3.12/site-packages/colorama/ansitowin32.py", line 47, in write
    self.__convertor.write(text)
  File "C:/Program Files/QMK_MSYS/mingw64/lib/python3.12/site-packages/colorama/ansitowin32.py", line 177, in write
    self.write_and_convert(text)
  File "C:/Program Files/QMK_MSYS/mingw64/lib/python3.12/site-packages/colorama/ansitowin32.py", line 205, in write_and_convert
    self.write_plain_text(text, cursor, len(text))
  File "C:/Program Files/QMK_MSYS/mingw64/lib/python3.12/site-packages/colorama/ansitowin32.py", line 211, in write_plain_text
    self.wrapped.flush()
OSError: [Errno 22] Invalid argument
Exception ignored in: <colorama.ansitowin32.StreamWrapper object at 0x0000029314c148c0>
OSError: [Errno 22] Invalid argument
Ψ Compiling keymap with make -r -R -f builddefs/build_keyboard.mk -s KEYBOARD=gowla/e_rgb KEYMAP=default KEYBOARD_FILESAFE=gowla_e_rgb TARGET=gowla_e_rgb_default VERBOSE=false COLOR=true SILENT=false QMK_BIN="qmk"

⚠ gowla/e_rgb: Feature bootmagic is specified in both info.json ({'bootmagic': False, 'command': False, 'console': False, 'extrakey': True, 'mousekey': False, 'nkro': True}) and rules.mk (False). The rules.mk value wins.
⚠ gowla/e_rgb: Feature mousekey is specified in both info.json ({'bootmagic': False, 'command': False, 'console': False, 'extrakey': True, 'mousekey': False, 'nkro': True}) and rules.mk (False). The rules.mk value wins.
⚠ gowla/e_rgb: Feature extrakey is specified in both info.json ({'bootmagic': False, 'command': False, 'console': False, 'extrakey': True, 'mousekey': False, 'nkro': True}) and rules.mk (True). The rules.mk value wins.
⚠ gowla/e_rgb: Feature console is specified in both info.json ({'bootmagic': False, 'command': False, 'console': False, 'extrakey': True, 'mousekey': False, 'nkro': True, 'encoder': True}) and rules.mk (False). The rules.mk value wins.
⚠ gowla/e_rgb: Feature command is specified in both info.json ({'bootmagic': False, 'command': False, 'console': False, 'extrakey': True, 'mousekey': False, 'nkro': True, 'encoder': True}) and rules.mk (False). The rules.mk value wins.
⚠ gowla/e_rgb: Feature nkro is specified in both info.json ({'bootmagic': False, 'command': False, 'console': False, 'extrakey': True, 'mousekey': False, 'nkro': True, 'encoder': True, 'sleep_led': False}) and rules.mk (True). The rules.mk value wins.
⚠ gowla/e_rgb: DIODE_DIRECTION in config.h is overwriting diode_direction in info.json
☒ gowla/e_rgb: RGB_DI_PIN in config.h is no longer a valid option and should be replaced with WS2812_DI_PIN or APA102_DI_PIN
⚠ gowla/e_rgb: UNUSED_PINS in config.h is deprecated and will be removed at a later date
⚠ gowla/e_rgb: DEVICE_VER in config.h is deprecated in favor of `usb.device_version` in info.json and will be removed at a later date
⚠ gowla/e_rgb: DEVICE_VER in config.h is overwriting usb.device_version in info.json
⚠ gowla/e_rgb: MANUFACTURER in config.h is deprecated in favor of `manufacturer` in info.json and will be removed at a later date
⚠ gowla/e_rgb: MANUFACTURER in config.h is overwriting manufacturer in info.json
⚠ gowla/e_rgb: PRODUCT in config.h is deprecated in favor of `keyboard_name` in info.json and will be removed at a later date
⚠ gowla/e_rgb: PRODUCT_ID in config.h is deprecated in favor of `usb.pid` in info.json and will be removed at a later date
⚠ gowla/e_rgb: PRODUCT_ID in config.h is overwriting usb.pid in info.json
⚠ gowla/e_rgb: VENDOR_ID in config.h is deprecated in favor of `usb.vid` in info.json and will be removed at a later date
⚠ gowla/e_rgb: VENDOR_ID in config.h is overwriting usb.vid in info.json
⚠ gowla/e_rgb: Matrix pins are specified in both info.json and config.h, the config.h values win.
☒ gowla/e_rgb: Invalid keyboard.json location detected: keyboards/gowla/keyboard.json.
☒ gowla/e_rgb: LAYOUT_ortho_3x3: Layout macro should not be defined within ".h" files.
⚠ gowla/e_rgb: Feature bootmagic is specified in both info.json ({'bootmagic': False, 'command': False, 'console': False, 'extrakey': True, 'mousekey': False, 'nkro': True}) and rules.mk (False). The rules.mk value wins.
⚠ gowla/e_rgb: Feature mousekey is specified in both info.json ({'bootmagic': False, 'command': False, 'console': False, 'extrakey': True, 'mousekey': False, 'nkro': True}) and rules.mk (False). The rules.mk value wins.
⚠ gowla/e_rgb: Feature extrakey is specified in both info.json ({'bootmagic': False, 'command': False, 'console': False, 'extrakey': True, 'mousekey': False, 'nkro': True}) and rules.mk (True). The rules.mk value wins.
⚠ gowla/e_rgb: Feature console is specified in both info.json ({'bootmagic': False, 'command': False, 'console': False, 'extrakey': True, 'mousekey': False, 'nkro': True, 'encoder': True}) and rules.mk (False). The rules.mk value wins.
⚠ gowla/e_rgb: Feature command is specified in both info.json ({'bootmagic': False, 'command': False, 'console': False, 'extrakey': True, 'mousekey': False, 'nkro': True, 'encoder': True}) and rules.mk (False). The rules.mk value wins.
⚠ gowla/e_rgb: Feature nkro is specified in both info.json ({'bootmagic': False, 'command': False, 'console': False, 'extrakey': True, 'mousekey': False, 'nkro': True, 'encoder': True, 'sleep_led': False}) and rules.mk (True). The rules.mk value wins.
⚠ gowla/e_rgb: DIODE_DIRECTION in config.h is overwriting diode_direction in info.json
☒ gowla/e_rgb: RGB_DI_PIN in config.h is no longer a valid option and should be replaced with WS2812_DI_PIN or APA102_DI_PIN
⚠ gowla/e_rgb: UNUSED_PINS in config.h is deprecated and will be removed at a later date
⚠ gowla/e_rgb: DEVICE_VER in config.h is deprecated in favor of `usb.device_version` in info.json and will be removed at a later date
⚠ gowla/e_rgb: DEVICE_VER in config.h is overwriting usb.device_version in info.json
⚠ gowla/e_rgb: MANUFACTURER in config.h is deprecated in favor of `manufacturer` in info.json and will be removed at a later date
⚠ gowla/e_rgb: MANUFACTURER in config.h is overwriting manufacturer in info.json
⚠ gowla/e_rgb: PRODUCT in config.h is deprecated in favor of `keyboard_name` in info.json and will be removed at a later date
⚠ gowla/e_rgb: PRODUCT_ID in config.h is deprecated in favor of `usb.pid` in info.json and will be removed at a later date
⚠ gowla/e_rgb: PRODUCT_ID in config.h is overwriting usb.pid in info.json
⚠ gowla/e_rgb: VENDOR_ID in config.h is deprecated in favor of `usb.vid` in info.json and will be removed at a later date
⚠ gowla/e_rgb: VENDOR_ID in config.h is overwriting usb.vid in info.json
⚠ gowla/e_rgb: Matrix pins are specified in both info.json and config.h, the config.h values win.
☒ gowla/e_rgb: Invalid keyboard.json location detected: keyboards/gowla/keyboard.json.
☒ gowla/e_rgb: LAYOUT_ortho_3x3: Layout macro should not be defined within ".h" files.
Generating: .build/obj_gowla_e_rgb_default/src/info_deps.d                                          [OK]
⚠ gowla/e_rgb: Feature bootmagic is specified in both info.json ({'bootmagic': False, 'command': False, 'console': False, 'extrakey': True, 'mousekey': False, 'nkro': True}) and rules.mk (False). The rules.mk value wins.
⚠ gowla/e_rgb: Feature mousekey is specified in both info.json ({'bootmagic': False, 'command': False, 'console': False, 'extrakey': True, 'mousekey': False, 'nkro': True}) and rules.mk (False). The rules.mk value wins.
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

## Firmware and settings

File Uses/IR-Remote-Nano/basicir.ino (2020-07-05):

#define IRSND_OUTPUT_PIN 11
#include <Keypad.h>
#include <irsndSelectMain15Protocols.h>
#include <irsnd.c.h>

IRMP_DATA irsnd_data;

// ====== INIT KEYPAD ======
const byte ROWS = 3; //four rows
const byte COLS = 3; //three columns
char keys[ROWS][COLS] = {
  {'1','2','3'},
  {'4','5','6'},
  {'7','8','9'}
};
byte rowPins[ROWS] = {2, 3, 4}; //connect to the row pinouts of the keypad
byte colPins[COLS] = {9, 8, 7}; //connect to the column pinouts of the keypad


Keypad keypad = Keypad( makeKeymap(keys), rowPins, colPins, ROWS, COLS );


void setup(){
    Serial.begin(9600);
    irsnd_init();
    irsnd_data.flags = 0;
    keypad.setHoldTime(100);
}

// ====== IR CODE STORAGE ======
char AppleIRCodes[10] = {
  0x0, // 0: Dummy
  0x0, // 1: Blank
  0xB, // 2: Up, Volume Up
  0x0, // 3: Blank
  0x8, // 4: Left, Previous
  0x4, // 5: Center, Play/Pause
  0x7, // 6: Right, Next
  0x0, // 7: Blank
  0xD, // 8: Down, Volume Down
  0x0 // 9: Blank
};


void loop(){
  char key = keypad.getKey();
  KeyState state = keypad.getState();
  
  if (key || state == HOLD) {
    irsnd_data.protocol = IRMP_APPLE_PROTOCOL;
    irsnd_data.address = 0x82;
    if (key) {
      irsnd_data.command = AppleIRCodes[key - '0'];
    } else {
      delay(5);
    }
    
    irsnd_send_data(&irsnd_data, false);
  }   
}

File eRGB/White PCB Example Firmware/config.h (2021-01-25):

/*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
You should have received a copy of the GNU General Public License
along with this program.  If not, see <http://www.gnu.org/licenses/>.
*/

#pragma once

#include "config_common.h"

/* USB Device descriptor parameter */
#define VENDOR_ID       0xFEED
#define PRODUCT_ID      0x0007
#define DEVICE_VER      0x0001
#define MANUFACTURER    Gowla
#define PRODUCT         Gowla Macro eRGB

/* Matrix size */
#define MATRIX_ROWS 3
#define MATRIX_COLS 3

/* Pin-out */
#define MATRIX_ROW_PINS { D1, D0, D4 }
#define MATRIX_COL_PINS { B5, B4, E6 }
#define UNUSED_PINS

/* ROW2COL */
#define DIODE_DIRECTION ROW2COL

/* RGB */
#define RGB_DI_PIN B6
#define RGBLED_NUM 3
#define RGBLIGHT_EFFECT_STATIC_LIGHT
#define RGBLIGHT_EFFECT_RGB_TEST
#define RGBLIGHT_EFFECT_RAINBOW_MOOD
#define RGBLIGHT_EFFECT_KNIGHT
#define RGBLIGHT_HUE_STEP 10
#define RGBLIGHT_SAT_STEP 17
#define RGBLIGHT_LIMIT_VAL 225

/* Rotary Encoder*/
#define ENCODERS_PAD_A { B2 }
#define ENCODERS_PAD_B { B3 }
#define ENCODER_RESOLUTION 4

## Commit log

2020-06-30 headers not spacers
2020-07-04 solder order
2020-07-05 Revisions and RGB version wip
    [Gerber_BoardOutline.GKO, Gerber_BottomLayer.GBL, Gerber_BottomPasteMaskLayer.GBP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]
2020-07-05 rgb board
2020-07-05 Added Dan's use case
2020-07-05 Move to Gerbers Folder
    [Gerber_BoardOutline.GKO, Gerber_BottomLayer.GBL, Gerber_BottomPasteMaskLayer.GBP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]
2020-10-21 STL Files WIP
    STL Files for work in progress case design.
    [bottom_plate.stl, top_plate.stl]
2020-11-02 Case images and stl
    New case STL for 3D printing, rendered image of case design.
    [bottom_plate_no_holes.stl]
2020-11-02 Case design update
2020-12-03 Cases update
    Cases for 3D Printing.
    [bottom case M2 holes.stl, bottom case.stl, bottom_plate.stl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]
2020-12-03 eRGB PCB Images
2020-12-03 eRGB PCB Image
2020-12-03 Removal of use case images
2020-12-03 top plate image
2020-12-03 Top Plates and Hardware
2020-12-19 PCB Section Links
2020-12-19 top plate update
2021-01-02 Early Example Firmware for eRGB PCB
    Supports RGB and Rotary encoder.
2021-01-03 Assembly tips for eRGB
2021-01-18 case to render image
2021-01-18 Case r2r image
2021-01-25 Case and Built Availablity
2023-03-14 bottom stl for tapedeck
    [MEK-L-tapedeck-bottom.stl]

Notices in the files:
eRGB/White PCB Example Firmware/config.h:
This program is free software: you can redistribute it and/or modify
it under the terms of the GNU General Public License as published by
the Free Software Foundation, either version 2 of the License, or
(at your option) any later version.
